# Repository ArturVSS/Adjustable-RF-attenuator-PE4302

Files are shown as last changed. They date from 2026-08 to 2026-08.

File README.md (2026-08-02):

Regulowany tłumik RF na module PE4302 z obsługą przez WWW.

IMG_20260802_221311979_HDR

Przy pomiarach torów w.cz bardzo często operujemy poziomami sygnałów które są zbyt wysokie. Najprostszym sposobem aby obniżyć poziom jest użycie tłumika. O ile stałe tłumiki są  dobrym rozwiązaniem ale nieraz podczas pomiaru trzeba zmienić poziom tłumienia. Przełączanie ręczne sprawia dużo problemów i w takim przypadku najlepszym rozwiązaniem jest tłumik regulowany. Budowanie tłumików na rezystorach jest możliwe ale zakup dobrych rezystorów 1% jest utrudnione i może okazać się, ze zbudowanie przełączanego  tłumika będzie kosztowne. I tu pomocny okazuje się układ tłumika regulowanego PE4302 firmy Peregrine Semiconductor Corp. Charakteryzuje się dobrymi parametrami, pracą do 4GHz i dwoma sposobami sterowania: szeregowy i równoległy. Postanowiłem wykorzystać ten moduł to zbudowania regulowanego tłumika. Jako platformę sterującą wykorzystałem moduł ESP32 a do wizualizacji i sterowania moduł zawierający wyświetlacz OLED 1.3” i enkoder obrotowy z przyciskiem. Jako, że zakupiony moduł ma wyprowadzony tylko interfejs równoległy wymusiło to na mnie taki rodzaj sterowania.

Tłumik regulowany PE4302 firmy Peregrine Semiconductor Corp

pe4302

PE4302 to 6-bitowy cyfrowy tłumik skokowy RF (DSA) o wysokiej liniowości, obejmujący zakres tłumienia 31,5 dB w krokach co 0,5 dB. Zapewnia zarówno równoległy, jak i szeregowy interfejs sterowania CMOS, działa na pojedynczym zasilaniu 3 V i utrzymuje wysoką dokładność tłumienia w funkcji częstotliwości i temperatury. Posiada również unikalny interfejs sterowania, który pozwala użytkownikowi wybrać początkowy stan tłumienia po włączeniu zasilania. PE4302 charakteryzuje się bardzo niskim tłumieniem wtrąceniowym i niskim poborem mocy. Cały układ jest umieszczony w obudowie QFN o wymiarach 4x4 mm. PE4302 jest produkowany w technologii UltraCMOS firmy Peregrine, opatentowanej odmianie technologii krzemu na izolatorze (SOI) na podłożu szafirowym, oferującej wydajność GaAs z ekonomią i integracją konwencjonalnych CMOS.

Podstawowe parametry:

•	Tłumienie: co 0,5 dB do 31,5 dB

•	Dokładność: do 1GHz +/-0.1dB +3%, powyżej 1GHz +/-0.15dB +5% 

•	Pasmo przenoszenia: od DC do 4 GHz

•	IP3 wejściowe: 52dB

•	Maksymalna moc wchodząca: +24dBm

•	Strata wtrąceniowa: 1.5dB

•	Szybkość przełączania: 1uS

•	Napięcie robocze: 3V

•	Pobór prądu: 100uA

Schemat wewnętrzny:

pe_inside

Schemat podstawowy układu PE4302:

pe_sch

Charakterystyka tłumienia w paśmie:

pe_att

Elementy wykorzystane do budowy tłumika:

pe4302
esp32
oled

Opis układu tłumika.
Układ jest prosty. Sterowanie tłumika połączone jest z ESP32 ośmioma przewodami: zasilanie, masa i 6 sygnałów sterujących. Wyświetlacz OLED pracuje na magistrali i2c więc oprócz zasilania i masy wymaga tylko dwóch przewodów. Wraz z wyświetlaczem na płytce jest zainstalowany enkoder, on podłączony jest trzema przewodami: dwa do impulsów enkodera i jeden do przycisku, masa jest wykorzystana z masy wyświetlacza.
PE4302:

•	GPIO25 -> C0.5

•	GPIO26 -> C1

•	GPIO27 -> C2

•	GPIO32 -> C4

•	GPIO33 -> C8

•	GPIO23 -> C16

OLED:

•	GPIO21 -> SDA

•	GPIO22 -> SCL

Enkoder:

•	GPIO19 -> A 

•	GPIO18 -> B

•	GPIO5 -> SW 

Do wyświetlacza OLED podłączyłem napięcie 5V a do modułu PE4302 napięcie 3V z modułu ESP32.

Przed kompilacją należy ustawić login i hasło do sieci wifi, linia 42 i 43:

String wifiSSID     = "SSID";

String wifiPassword = "password";

Parametry te można po uruchomieniu z poziomu strony WWW zmienić.

Obsługa tłumika.
Po włączeniu zasilania na wyświetlaczu pojawia się poziom tłumienia. Obracanie pokrętłem enkodera powoduje zmianę tłumienia o 0,5dB. Naciśnięcie przycisku w enkoderze powoduje wyzerowanie tłumika. W dolnej linii na wyświetlaczu widać adres IP pod którym dostępna jest strona WWW do obsługi tłumika.

www

Strona WWW wyświetla poziom tłumienia, umożliwia wpisanie ręczne wartości tłumienia, zmianę z krokiem co 0,5dB jak i wyzerowanie tłumienia.  Dodatkowo mamy 64 przyciski wpisania „szybkiej wartości” tłumienia. Kliknięcie w przycisk od razu wpisze odpowiednią wartość tłumienia.  
W dolnej części znajduje się okno z możliwością wpisania innej sieci wifi i hasła do niej.

Całość została umieszczona w wydrukowanej na drukarce 3d obudowie z materiału PET-G. Z boku obudowy znajdują się dwa gniazda BNC podłączone do płytki tłumika. Całość zasilana jest z zasilacza 5V poprzez gniazdo USB-C z tyłu obudowy. Cały układ pobiera poniżej 1W mocy.

Opracowanie:

Artur SP3VSS

http://sp3vss.eu

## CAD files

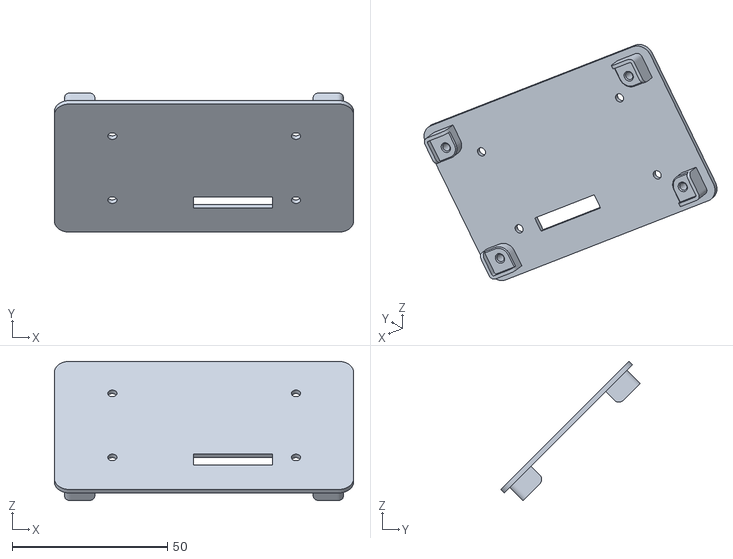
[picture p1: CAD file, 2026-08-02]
STL/OLED ATT.stl
96.4 x 44.9 x 44.9

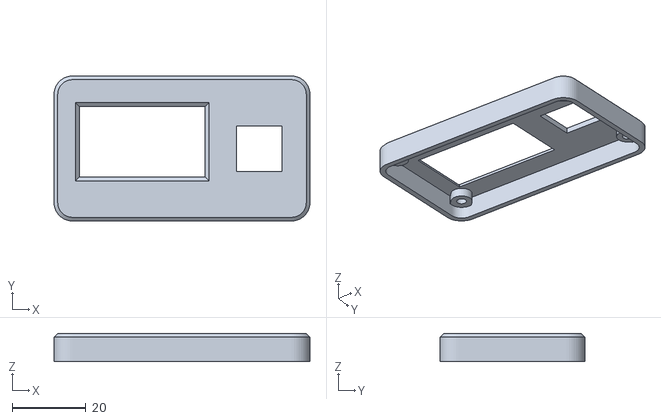
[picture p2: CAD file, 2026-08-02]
STL/OLED ATT frame.stl
69.2 x 39.2 x 7.60

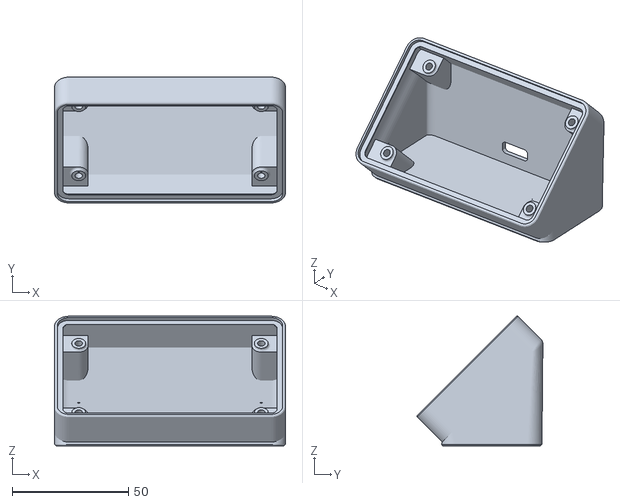
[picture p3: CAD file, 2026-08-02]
STL/CYD Desk Buddy.stl
99.2 x 54.0 x 55.6

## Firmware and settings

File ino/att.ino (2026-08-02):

//Copyright by VSS 2026
//Not for commercial use  

#include <Arduino.h>
#include <Wire.h>
#include <WiFi.h>
#include <WebServer.h>
#include <U8g2lib.h>
#include <Preferences.h>

// ============================================================
// ESP32 + SH1106 OLED + enkoder + PE4302 + WWW + NVS WiFi
//
// OLED:
// SDA = GPIO21
// SCL = GPIO22
//
// Enkoder:
// A = GPIO19
// B = GPIO18
//
// Przycisk resetu tłumienia:
// GPIO5
//
// PE4302:
// GPIO25 -> C0.5
// GPIO26 -> C1
// GPIO27 -> C2
// GPIO32 -> C4
// GPIO33 -> C8
// GPIO23 -> C16
//
// P/S -> GND
// LE  -> 3.3V
// ============================================================

Preferences preferences;

// -------------------------
// Domyślne dane WiFi
// -------------------------
String wifiSSID = "SSID";
String wifiPassword = "password";

const bool USE_STATIC_IP = false;

IPAddress local_IP(192, 168, 1, 222);
IPAddress gateway(192, 168, 1, 1);
IPAddress subnet(255, 255, 255, 0);
IPAddress primaryDNS(8, 8, 8, 8);
IPAddress secondaryDNS(1, 1, 1, 1);

// -------------------------
// Web server
// -------------------------
WebServer server(80);

// -------------------------
// OLED SH1106 I2C
// -------------------------
U8G2_SH1106_128X64_NONAME_F_HW_I2C u8g2(U8G2_R0, U8X8_PIN_NONE);

// -------------------------
// GPIO OLED
// -------------------------
static const uint8_t PIN_I2C_SDA = 21;
static const uint8_t PIN_I2C_SCL = 22;

// -------------------------
// GPIO enkoder / przycisk
// -------------------------
static const uint8_t PIN_ENC_A = 19;
static const uint8_t PIN_ENC_B = 18;
static const uint8_t PIN_BUTTON = 5;

// -------------------------
// GPIO PE4302
// -------------------------
static const uint8_t PIN_C05 = 25;
static const uint8_t PIN_C1  = 26;
static const uint8_t PIN_C2  = 27;
static const uint8_t PIN_C4  = 32;
static const uint8_t PIN_C8  = 33;
static const uint8_t PIN_C16 = 23;

// -------------------------
// Tłumienie:
// 0  = 0.0 dB
// 63 = 31.5 dB
// -------------------------
volatile int attenuationSteps = 0;
int lastDrawnSteps = -1;

int lastClkState = HIGH;

bool buttonState = HIGH;
bool lastButtonState = HIGH;
unsigned long lastButtonDebounce = 0;

String lastIpString = "";
unsigned long lastIpCheckMs = 0;

// ============================================================
// WiFi / NVS
// ============================================================
void loadWifiFromNVS() {
  preferences.begin("wifi", true);
  wifiSSID = preferences.getString("ssid", "Xiaomi2G");
  wifiPassword = preferences.getString("pass", "dupablada");
  preferences.end();
}

void saveWifiToNVS(const String& ssid, const String& pass) {
  preferences.begin("wifi", false);
  preferences.putString("ssid", ssid);
  preferences.putString("pass", pass);
  preferences.end();
}

String getIpString() {
  if (WiFi.status() == WL_CONNECTED) {
    return WiFi.localIP().toString();
  }

  return "No IP";
}

void connectWiFi() {
  WiFi.mode(WIFI_STA);

  if (USE_STATIC_IP) {
    WiFi.config(local_IP, gateway, subnet, primaryDNS, secondaryDNS);
  }

  WiFi.begin(wifiSSID.c_str(), wifiPassword.c_str());

  unsigned long startAttempt = millis();

  while (WiFi.status() != WL_CONNECTED &&
         millis() - startAttempt < 20000) {
    delay(500);
  }
}

void reconnectWiFi() {
  WiFi.disconnect(true, true);
  delay(500);
  connectWiFi();
}

// ============================================================
// Tłumik PE4302
// ============================================================
String attenuationToString(int steps) {
  steps = constrain(steps, 0, 63);

  int whole = steps / 2;
  bool half = (steps % 2) != 0;

  if (half) {
    return String(whole) + ".5";
  }

  return String(whole) + ".0";
}

int parseAttenuationToSteps(String s) {
  s.trim();
  s.replace(",", ".");

  float v = s.toFloat();

  if (v < 0.0f) v = 0.0f;
  if (v > 31.5f) v = 31.5f;

  int steps = (int)(v * 2.0f + 0.5f);

  return constrain(steps, 0, 63);
}

void setPE4302(int steps) {
  steps = constrain(steps, 0, 63);

  digitalWrite(PIN_C05, (steps & 0x01) ? HIGH : LOW);
  digitalWrite(PIN_C1,  (steps & 0x02) ? HIGH : LOW);
  digitalWrite(PIN_C2,  (steps & 0x04) ? HIGH : LOW);
  digitalWrite(PIN_C4,  (steps & 0x08) ? HIGH : LOW);
  digitalWrite(PIN_C8,  (steps & 0x10) ? HIGH : LOW);
  digitalWrite(PIN_C16, (steps & 0x20) ? HIGH : LOW);
}

void applyAttenuation(int steps) {
  attenuationSteps = constrain(steps, 0, 63);
  setPE4302(attenuationSteps);
}

// ============================================================
// OLED
// ============================================================
void drawScreen(int steps) {
  String txt = attenuationToString(steps);
  String ip = getIpString();

  u8g2.clearBuffer();

  u8g2.setFont(u8g2_font_6x10_tf);
  int16_t titleX =
    (128 - u8g2.getStrWidth("Adjustable attenuator")) / 2;
  u8g2.drawStr(titleX, 10, "Adjustable attenuator");

  u8g2.drawFrame(0, 14, 128, 34);

  u8g2.setFont(u8g2_font_7x13B_tf);
  u8g2.drawStr(6, 35, "ATT");

  u8g2.setFont(u8g2_font_logisoso20_tf);
  int16_t valueWidth = u8g2.getStrWidth(txt.c_str());
  int16_t valueX = 92 - valueWidth;

  if (valueX < 30) {
    valueX = 30;
  }

  u8g2.drawStr(valueX, 41, txt.c_str());

  u8g2.setFont(u8g2_font_6x10_tf);
  u8g2.drawStr(100, 36, "dBm");

  u8g2.setFont(u8g2_font_5x8_tf);
  String ipLine = "IP: " + ip;

  int16_t ipX =
    (128 - u8g2.getStrWidth(ipLine.c_str())) / 2;

  if (ipX < 0) {
    ipX = 0;
  }

  u8g2.drawStr(ipX, 62, ipLine.c_str());
  u8g2.sendBuffer();
}

// ============================================================
// WWW
// ============================================================
String makeHtmlPage() {
  String html;
  html.reserve(25000);

  html += R"rawliteral(
<!DOCTYPE html>
<html lang="pl">
<head>
<meta charset="utf-8">
<meta name="viewport" content="width=device-width,initial-scale=1">
<title>Adjustable Attenuator</title>

<style>
  html {
    background: #111;
  }

  body {
    font-family: Arial, sans-serif;
    background: #111;
    color: #eee;
    margin: 0;
    padding: 20px;
    text-align: center;
  }

  .wrap {
    max-width: 1300px;
    margin: 0 auto;
  }

  .box {
    background: #1b1b1b;
    border: 1px solid #3c3c3c;
    border-radius: 14px;
    padding: 20px;
    margin-bottom: 16px;
  }

  .title {
    font-size: 30px;
    color: #fff;
    margin-bottom: 18px;
    font-weight: bold;
  }

  .valueRow {
    display: grid;
    grid-template-columns: 1fr auto 1fr;
    align-items: end;
    color: #66ff33;
  }

  .attLabel {
    font-size: 56px;
    font-weight: bold;
    line-height: 1;
    color: #66ff33;
    justify-self: start;
    text-align: left;
  }

  .centerWrap {
    display: flex;
    align-items: end;
    justify-content: center;
  }

  .mainValue {
    font-size: 224px;
    line-height: 1;
    font-weight: bold;
    color: #66ff33;
  }

  .unit {
    font-size: 56px;
    line-height: 1;
    font-weight: bold;
    color: #66ff33;
    justify-self: end;
    text-align: right;
  }

  .ctrlRow {
    display: flex;
    flex-wrap: wrap;
    gap: 12px;
    align-items: center;
    justify-content: center;
  }

  .ctrlInput {
    font-size: 28px;
    padding: 12px 14px;
    width: 180px;
    text-align: center;
    border-radius: 10px;
    border: 1px solid #666;
    background: #0f0f0f;
    color: #66ff33;
  }

  .btn {
    font-size: 22px;
    font-weight: bold;
    padding: 12px 20px;
    border-radius: 10px;
    border: 1px solid #4a4a4a;
    background: #1f1f1f;
    color: #66ff33;
    cursor: pointer;
    min-width: 90px;
  }

  .btn:hover {
    background: #2a2a2a;
  }

  .hint {
    font-size: 15px;
    color: #8f8f8f;
    margin-top: 10px;
  }

  .presetGrid {
    display: grid;
    grid-template-columns: repeat(16, 1fr);
    gap: 6px;
    width: 100%;
    margin: 18px auto 0;
  }

  .presetBtn {
    font-size: 16px;
    font-weight: bold;
    min-height: 40px;
    padding: 8px 2px;
    border-radius: 7px;
    border: 1px solid #4a4a4a;
    background: #1f1f1f;
    color: #66ff33;
    cursor: pointer;
  }

  .presetBtn:hover {
    background: #2a2a2a;
  }

  .netWrap {
    display: flex;
    flex-direction: column;
    gap: 18px;
  }

  .netLine {
    display: flex;
    flex-wrap: wrap;
    gap: 28px;
    justify-content: center;
    align-items: center;
    font-size: 20px;
    color: #ccc;
  }

  .wifiTitle {
    font-size: 22px;
    color: #fff;
    font-weight: bold;
    margin-top: 4px;
  }

  .wifiForm {
    display: grid;
    grid-template-columns: 1fr 1fr auto;
    gap: 12px;
    align-items: center;
  }

  .wifiInput {
    font-size: 20px;
    padding: 12px 14px;
    border-radius: 10px;
    border: 1px solid #666;
    background: #0f0f0f;
    color: #fff;
    min-width: 0;
  }

  .copy {
    font-size: 18px;
    color: #aaa;
  }

  @media (max-width: 1100px) {
    .presetGrid {
      grid-template-columns: repeat(8, 1fr);
    }
  }

  @media (max-width: 820px) {
    .wifiForm {
      grid-template-columns: 1fr;
    }

    .netLine {
      gap: 12px;
      flex-direction: column;
    }

    .mainValue {
      font-size: 82px;
    }

    .attLabel,
    .unit {
      font-size: 40px;
    }

    .presetGrid {
      grid-template-columns: repeat(4, 1fr);
    }
  }
</style>

<script>
  async function refreshData() {
    try {
      const r = await fetch('/data');
      const d = await r.json();

      document.getElementById('val').textContent = d.att;
      document.getElementById('ip').textContent = d.ip;
      document.getElementById('mode').textContent = d.mode;
      document.getElementById('ssid').textContent = d.ssid;
    } catch (e) {
    }
  }

  async function setManual() {
    const v = document.getElementById('manualValue').value;
    await fetch('/set?value=' + encodeURIComponent(v));
    refreshData();
  }

  async function setPreset(value) {
    document.getElementById('manualValue').value = value.toFixed(1);
    await fetch('/set?value=' + encodeURIComponent(value.toFixed(1)));
    refreshData();
  }

  async function changeStep(delta) {
    await fetch('/step?delta=' + delta);
    refreshData();
  }

  async function setZero() {
    await fetch('/zero');
    refreshData();
  }

  async function saveWifi() {
    const ssid = document.getElementById('cfgssid').value;
    const pass = document.getElementById('cfgpass').value;

    const r = await fetch(
      '/savewifi?ssid=' + encodeURIComponent(ssid) +
      '&pass=' + encodeURIComponent(pass)
    );

    document.getElementById('saveinfo').textContent = await r.text();
    setTimeout(refreshData, 2000);
  }

  setInterval(refreshData, 1000);
  window.onload = refreshData;
</script>
</head>

<body>
<div class="wrap">

  <div class="box">
    <div class="title">Adjustable attenuator</div>

    <div class="valueRow">
      <div class="attLabel">ATT</div>

      <div class="centerWrap">
        <div id="val" class="mainValue">0.0</div>
      </div>

      <div class="unit">dBm</div>
    </div>
  </div>

  <div class="box">
    <div class="ctrlRow">
      <input
        id="manualValue"
        class="ctrlInput"
        type="text"
        inputmode="decimal"
        placeholder="np. 12.5"
      >

      <button class="btn" onclick="setManual()">ENTR</button>
      <button class="btn" onclick="changeStep(1)">+</button>
      <button class="btn" onclick="changeStep(-1)">-</button>
      <button class="btn" onclick="setZero()">ZERO</button>
    </div>

    <div class="hint">
      Zakres: 0.0 do 31.5 dB, krok zdalny: 0.5 dB
    </div>

    <div class="presetGrid">
)rawliteral";

  // 0.0, 0.5, 1.0 ... 31.5 dB
  for (int i = 0; i <= 63; i++) {
    float value = i * 0.5f;

    html += "<button class=\"presetBtn\" onclick=\"setPreset(";
    html += String(value, 1);
    html += ")\">";
    html += String(value, 1);
    html += "</button>";
  }

  html += R"rawliteral(
    </div>
  </div>

  <div class="box">
    <div class="netWrap">
      <div class="netLine">
        <div>SSID: <span id="ssid">)rawliteral";

  html += wifiSSID;

  html += R"rawliteral(</span></div>

        <div>
          Tryb IP:
          <span id="mode">)rawliteral";

  html += String(USE_STATIC_IP ? "STATIC" : "DHCP");

  html += R"rawliteral(</span>
        </div>

        <div>
          Adres IP:
          <span id="ip">)rawliteral";

  html += getIpString();

  html += R"rawliteral(</span>
        </div>
      </div>

      <div class="wifiTitle">Zmiana sieci WiFi</div>

      <div class="wifiForm">
        <input
          id="cfgssid"
          class="wifiInput"
          type="text"
          placeholder="Nowe SSID"
          value=")rawliteral";

  html += wifiSSID;

  html += R"rawliteral("
        >

        <input
          id="cfgpass"
          class="wifiInput"
          type="password"
          placeholder="Nowe hasło WiFi"
        >

        <button class="btn" onclick="saveWifi()">ZAPISZ</button>
      </div>

      <div id="saveinfo" class="hint">
        Dane zostaną zapisane w pamięci NVS i zostaną użyte
        po ponownym uruchomieniu.
      </div>
    </div>
  </div>

  <div class="box">
    <div class="copy">COPYRIGHT by VSS2026</div>
  </div>

</div>
</body>
</html>
)rawliteral";

  return html;
}

String makeJsonData() {
  String json = "{";

  json += "\"att\":\"" + attenuationToString(attenuationSteps) + "\",";
  json += "\"ip\":\"" + getIpString() + "\",";
  json += "\"mode\":\"" + String(USE_STATIC_IP ? "STATIC" : "DHCP") + "\",";
  json += "\"ssid\":\"" + wifiSSID + "\"";

  json += "}";

  return json;
}

void handleRoot() {
  server.send(200, "text/html; charset=utf-8", makeHtmlPage());
}

void handleData() {
  server.send(200, "application/json; charset=utf-8", makeJsonData());
}

void handleSet() {
  if (server.hasArg("value")) {
    int steps = parseAttenuationToSteps(server.arg("value"));
    applyAttenuation(steps);
  }

  server.send(
    200,
    "text/plain; charset=utf-8",
    attenuationToString(attenuationSteps)
  );
}

void handleStep() {
  int delta = 0;

  if (server.hasArg("delta")) {
    delta = server.arg("delta").toInt();
  }

  if (delta > 0) {
    applyAttenuation(attenuationSteps + 1);
  } else if (delta < 0) {
    applyAttenuation(attenuationSteps - 1);
  }

  server.send(
    200,
    "text/plain; charset=utf-8",
    attenuationToString(attenuationSteps)
  );
}

void handleZero() {
  applyAttenuation(0);

  server.send(
    200,
    "text/plain; charset=utf-8",
    attenuationToString(attenuationSteps)
  );
}

void handleSaveWifi() {
  if (server.hasArg("ssid") && server.hasArg("pass")) {
    String newSSID = server.arg("ssid");
    String newPass = server.arg("pass");

    newSSID.trim();
    newPass.trim();

    if (newSSID.length() > 0) {
      wifiSSID = newSSID;
      wifiPassword = newPass;

      saveWifiToNVS(wifiSSID, wifiPassword);

      server.send(
        200,
        "text/plain; charset=utf-8",
        "Zapisano. Trwa ponowne laczenie WiFi..."
      );

      reconnectWiFi();
      return;
    }
  }

  server.send(400, "text/plain; charset=utf-8", "Blad danych WiFi");
}

void startWebServer() {
  server.on("/", handleRoot);
  server.on("/data", handleData);
  server.on("/set", handleSet);
  server.on("/step", handleStep);
  server.on("/zero", handleZero);
  server.on("/savewifi", handleSaveWifi);

  server.begin();
}

// ============================================================
// Setup
// ============================================================
void setup() {
  Serial.begin(115200);

  pinMode(PIN_ENC_A, INPUT_PULLUP);
  pinMode(PIN_ENC_B, INPUT_PULLUP);
  pinMode(PIN_BUTTON, INPUT_PULLUP);

  Wire.begin(PIN_I2C_SDA, PIN_I2C_SCL);
  u8g2.begin();

  pinMode(PIN_C05, OUTPUT);
  pinMode(PIN_C1, OUTPUT);
  pinMode(PIN_C2, OUTPUT);
  pinMode(PIN_C4, OUTPUT);
  pinMode(PIN_C8, OUTPUT);
  pinMode(PIN_C16, OUTPUT);

  applyAttenuation(attenuationSteps);

  lastClkState = digitalRead(PIN_ENC_A);

  loadWifiFromNVS();
  connectWiFi();

  lastIpString = getIpString();

  drawScreen(attenuationSteps);
  lastDrawnSteps = attenuationSteps;

  startWebServer();
}

// ============================================================
// Loop
// ============================================================
void loop() {
  server.handleClient();

  bool oledNeedsRefresh = false;

  int clkState = digitalRead(PIN_ENC_A);

  if (clkState != lastClkState && clkState == LOW) {
    if (digitalRead(PIN_ENC_B) != clkState) {
      applyAttenuation(attenuationSteps + 1);
    } else {
      applyAttenuation(attenuationSteps - 1);
    }
  }

  lastClkState = clkState;

  bool reading = digitalRead(PIN_BUTTON);

  if (reading != lastButtonState) {
    lastButtonDebounce = millis();
  }

  if ((millis() - lastButtonDebounce) > 30) {
    if (reading != buttonState) {
      buttonState = reading;

      if (buttonState == LOW) {
        applyAttenuation(0);
      }
    }
  }

  lastButtonState = reading;

  if (lastDrawnSteps != attenuationSteps) {
    oledNeedsRefresh = true;
    lastDrawnSteps = attenuationSteps;
  }

  if (millis() - lastIpCheckMs > 1000) {
    lastIpCheckMs = millis();

    String currentIp = getIpString();

    if (currentIp != lastIpString) {
      lastIpString = currentIp;
      oledNeedsRefresh = true;
    }
  }

  if (oledNeedsRefresh) {
    drawScreen(attenuationSteps);
  }

  delay(2);
}

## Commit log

2026-08-02 Revise README for PE4302 adjustable RF attenuator
    Updated README.md with detailed information about the adjustable RF attenuator using the PE4302 module, including specifications, circuit details, and usage instructions.
2026-08-02 Update README with GPIO pin assignments
    Added GPIO pin assignments for PE4302, OLED, and encoder to README.
2026-08-02 Update README with enclosure and power details
    Added additional information about the device enclosure and power consumption.
2026-08-02 Add adjustable attenuator functionality with ESP32
    This file contains the implementation for an adjustable attenuator using an ESP32 with an OLED display, web server, and WiFi connectivity. It includes functions for handling WiFi settings, attenuatio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
